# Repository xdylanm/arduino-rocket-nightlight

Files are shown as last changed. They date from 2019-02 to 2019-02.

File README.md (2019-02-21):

# Space Shuttle Nightlight

Based on the [low poly space shuttle nightlight](https://www.thingiverse.com/thing:2957683) by [kelvin8r](https://www.thingiverse.com/kelvin8r). 

## Modifications

* Remixed the base print without supports (buttons are printed separately and glued on, so it prints upside down). Also re-sized the opening to hold an Adafruit Circuit Playground.
* Eventually used the [Digispark board](http://digistump.com/products/1) (I use a clone that works off of micro USB)
* Code to drive neo pixels supports a different color palette and different animations. Mode switching is triggered by [capacitive touch](https://playground.arduino.cc/Main/CapacitiveSensor)
* Printed on [Anycubic I3 Mega](http://www.anycubic3d.com/)
** Black base, white shuttle/exhaust

## Notes

* The digispark board (ATTiny85 based) with the micronucleus bootloader has a long delay (5s) between power on and the start of the program. When connected via USB, this is fine (the bootloader seems to look for a host and when it finds one, all is good). When _powered_ off the USB (e.g. through a wall plug), nothing happens for 5s+ -- don't panic.
* The digispark board recycles a couple of pins for USB. Those pins are not suitable for capacitive touch. They can drive the neo pixels, but can also put the pixels in an odd state when running data over the USB.
* Follow the printing instructions from the [make](https://www.thingiverse.com/thing:2957683) carefully:
  * Exhaust: _no infill_, 0.2mm layer, 0.4mm (2x) bottom layer, 1.2mm (6x) walls
  * Shuttle: 25% infill, 0.2mm layer (or whatever)
  * Base: 20% infill, 0.2mm layer (or whatever) -- print upside down to avoid supports

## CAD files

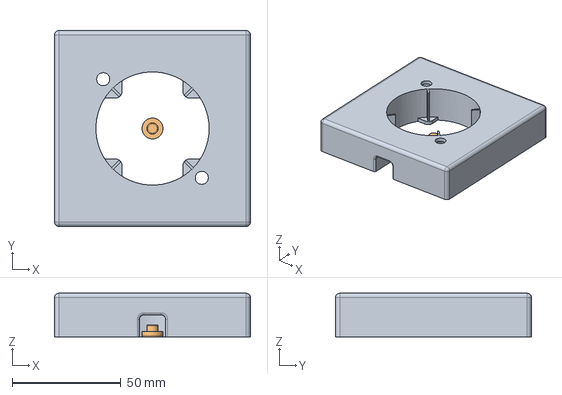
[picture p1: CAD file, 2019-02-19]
cad/circuit-playground-base.fcstd
90.0 x 90.0 x 20.0 mm

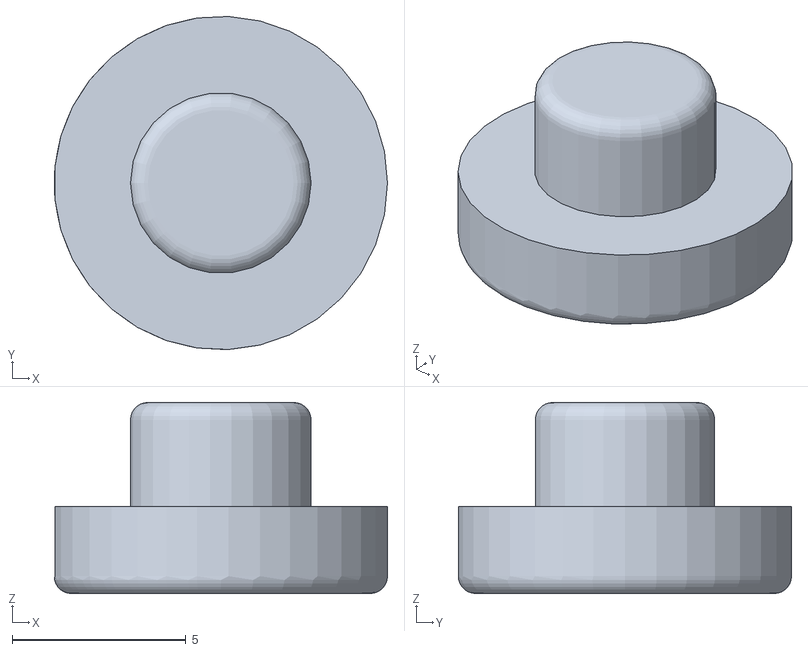
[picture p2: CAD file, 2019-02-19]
cad/rocket_base_circuit_playground_bump.stl
9.59 x 9.59 x 5.50

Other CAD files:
cad/rocket_base_circuit_playground.stl

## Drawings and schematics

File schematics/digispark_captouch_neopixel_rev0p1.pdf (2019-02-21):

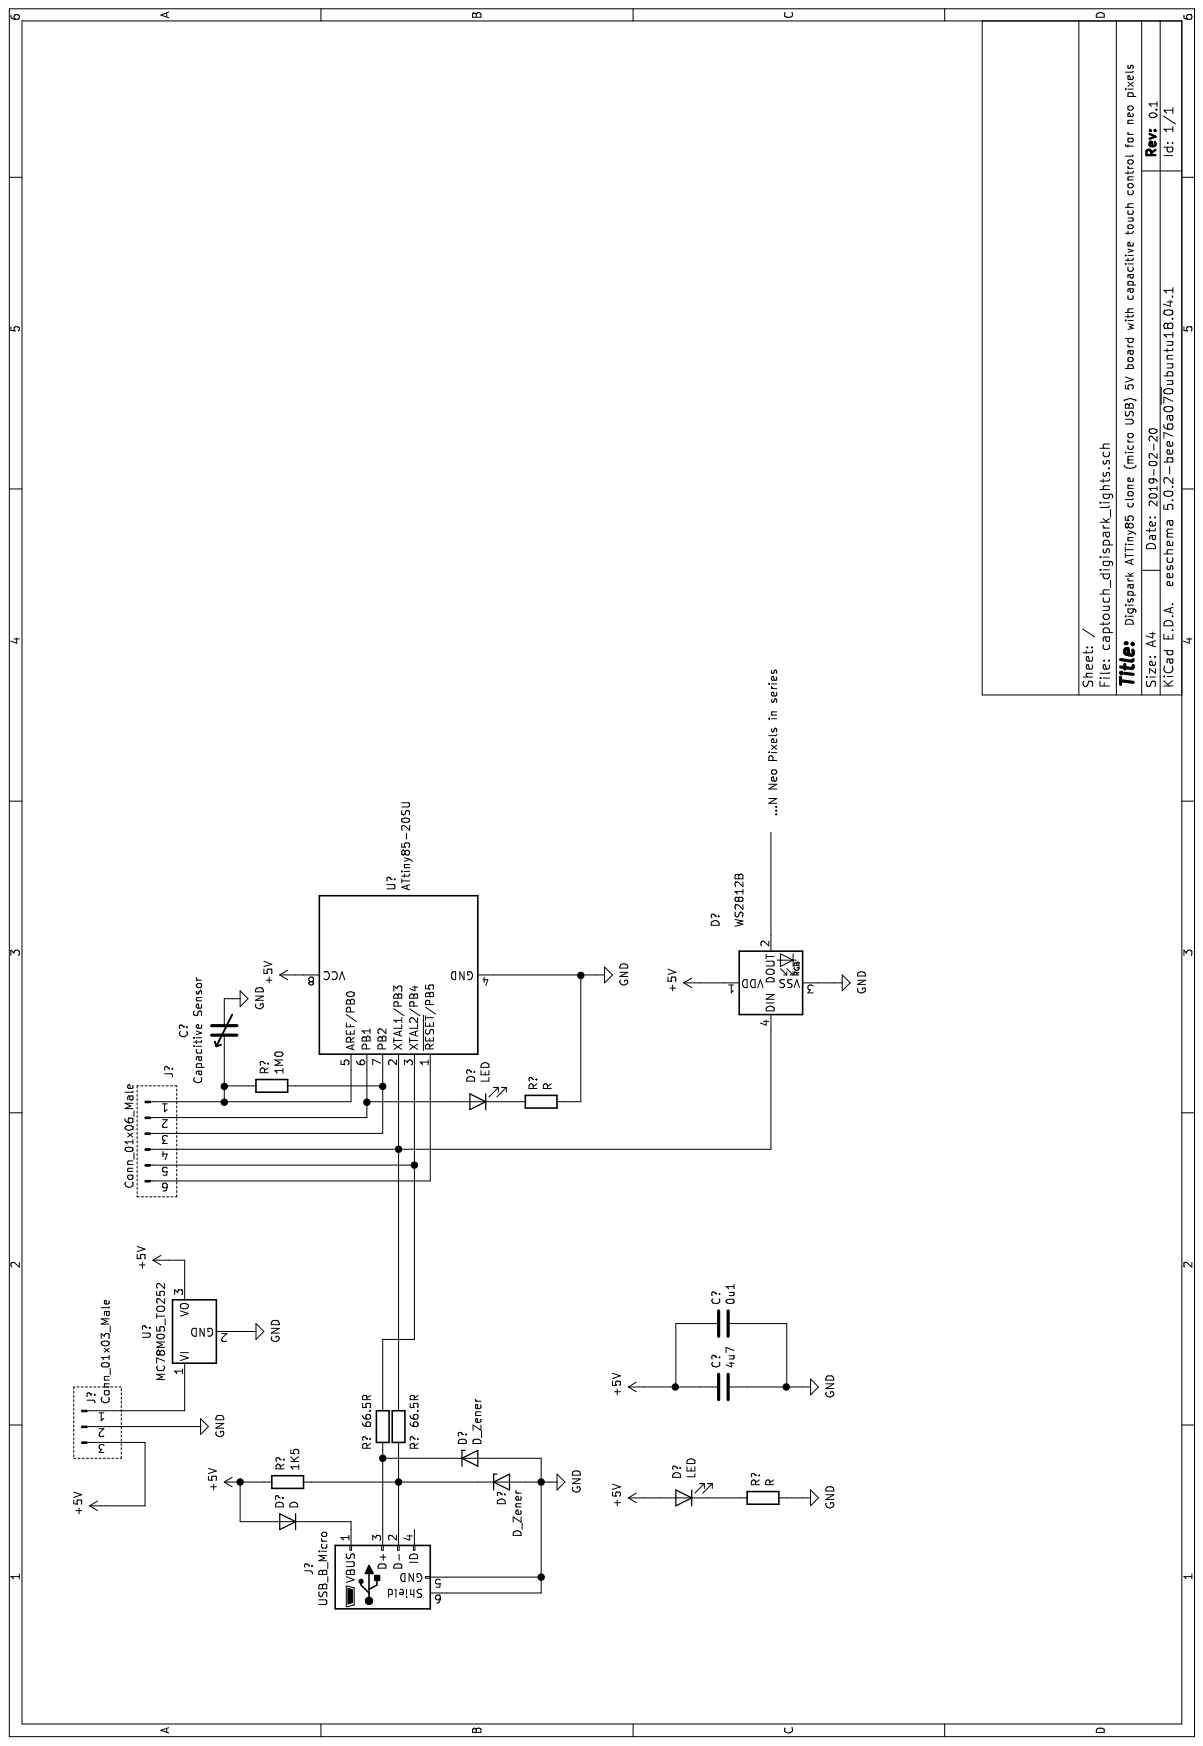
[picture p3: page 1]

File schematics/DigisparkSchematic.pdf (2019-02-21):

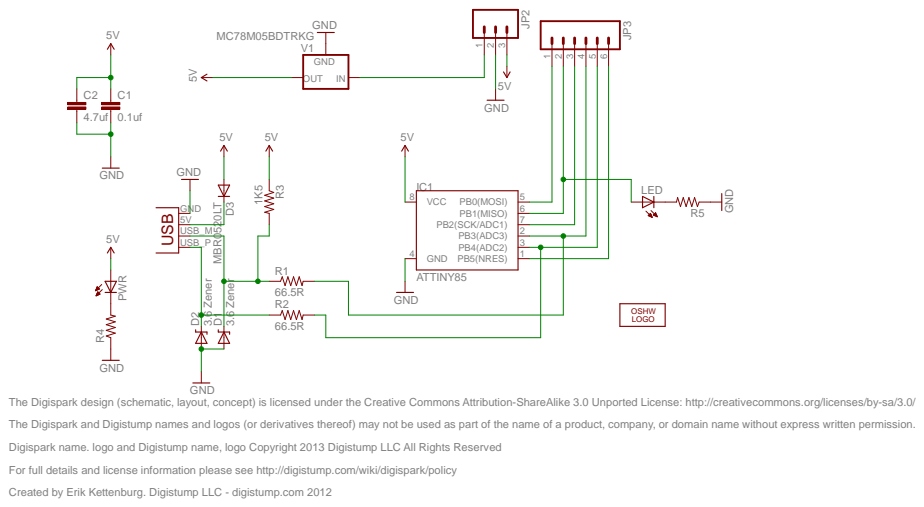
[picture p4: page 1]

The Digispark design (schematic, layout, concept) is licensed under the Creative Commons Attribution-ShareAlike 3.0 Unported License: http://creativecommons.org/licenses/by-sa/3.0/
The Digispark and Digistump names and logos (or derivatives thereof) may not be used as part of the name of a product, company, or domain name without express written permission.
Digispark name. logo and Digistump name, logo Copyright 2013 Digistump LLC All Rights Reserved
For full details and license information please see http://digistump.com/wiki/digispark/policy
Created by Erik Kettenburg. Digistump LLC - digistump.com 2012

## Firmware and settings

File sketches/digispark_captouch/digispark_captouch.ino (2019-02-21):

#include <Adafruit_NeoPixel.h>
#include <CapacitiveSensor.h>

#define PIN_DATA 4          // DIN to Neo Pixels
#define PIN_LED 1           // LED on Model B=PIN0, LED on Model A=PIN1
#define PIN_SENSE_READ 0    // Read for capacitive sensor
#define PIN_SENSE_DRIVE 2   // Drive V for capacitive sensor

#define N_PIXELS 6          // no more than 31

// threshold to detect a capacitive touch (0-999)
#define CAP_THRESHOLD 50 

// number of samples for capacitive sensor
#define CAP_NUM_SAMPLES 10 

// debounce timing (ms)
#define DEBOUNCE_MS 250 

#define PULSE_MS 125

// time to turn off (ticks = 1000/DEBOUNCE_MS*60*# minutes)
#define AUTO_OFF_TIMEOUT_TICKS 4800
uint32_t timeout_counter = 0;

// colors
const uint32_t palette[] = {
  0x8B0000, // dark red
  0xB22222, // firebrick
  0xFF0000, // red
  0xDC143C, // crimson
  0xFF6347, // tomato
  0xFF4500, // orange red
  0xFF8C00, // dark orange
  0xFFA500, // orange
  0xFFD700, // gold
  0xFFFF00, // yellow
  0xFFFFE0, // light yellow
  0xFFFACD  // lemon chiffon
};
uint8_t const num_colors = sizeof(palette)/sizeof(uint32_t);

int8_t pixel_color_index[N_PIXELS];
int8_t pixel_color_brightness[N_PIXELS];

enum NightLightMode {OFF=0, TWINKLE, PULSE, PULSE_OFF, NUM_MODES} night_light_state;
uint8_t pulse_level = 0;


Adafruit_NeoPixel pixels (N_PIXELS,PIN_DATA,NEO_GRBW+NEO_KHZ800);
CapacitiveSensor cap_sensor (PIN_SENSE_DRIVE, PIN_SENSE_READ);

bool cap_button_clicked() {
  long const val = cap_sensor.capacitiveSensor(CAP_NUM_SAMPLES); 
  return (val > CAP_THRESHOLD);
}

uint32_t scaled_color_quarter(uint8_t ipix, uint8_t num) {
  if (num == 4) {
    return palette[pixel_color_index[ipix]];
  } else if (num == 0) {
    return 0; 
  } else {
    uint8_t red   = (uint8_t)(palette[pixel_color_index[ipix]] >> 16);
    uint8_t green = (uint8_t)(palette[pixel_color_index[ipix]] >> 8);
    uint8_t blue  = (uint8_t)(palette[pixel_color_index[ipix]] >> 0);

    if (num == 2) {
      red   = red >> 1;
      green = green >> 1;
      blue  = blue >> 1;
    } else if (num == 1) {
      red   = red >> 2;
      green = green >> 2;
      blue  = blue >> 2;
    } else if (num == 3) {
      red   -= (red >> 2);
      green -= (green >> 2);
      blue  -= (blue >> 2);
    }
    return ((uint32_t)red << 16) | ((uint32_t)green << 8) | ((uint32_t)blue << 0);    
  }
}

void update_lights() 
{
  if (night_light_state == TWINKLE) {
    uint32_t brighten_mask = 0;
  
    long const nchange = random(N_PIXELS);  // brighten this many pixels
    for(long idelta = 0; idelta < nchange; ++idelta) {
      long const ipix = random(N_PIXELS);   // brighten this pixel
      brighten_mask |= 0x01 << ipix;
    }

    // saturating brighten/darken, then update 
    for(uint8_t ipix = 0; ipix < N_PIXELS; ++ipix) {
      if (brighten_mask & (0x01 << ipix)) {
        if ( pixel_color_brightness[ipix] < 3 ) { // 2 or lower --> 4
          pixel_color_brightness[ipix] += 2;
        } else if (pixel_color_brightness[ipix] > 5) {  // 6 or higher --> 4
          pixel_color_brightness[ipix] -= 2;
        } else {
          pixel_color_brightness[ipix] = 4;
        }
      } else {
        if ( pixel_color_brightness[ipix] > 1 && pixel_color_brightness[ipix] < 5 ) { // 2 to 4 --> 0
          pixel_color_brightness[ipix] -= 2;
        } else if (pixel_color_brightness[ipix] == 5) {  // 5 --> 8
          pixel_color_brightness[ipix] += 2;
        } else {
          pixel_color_brightness[ipix] = 0;
        }
       
        if (pixel_color_brightness[ipix] == 0) {  // change the color 
          pixel_color_index[ipix] = random(num_colors); 
        }
      }
    }
  } else if (night_light_state == PULSE) {
    if (pixel_color_brightness[0] == 0) { // new colors at 0
      for (uint8_t ipix = 0; ipix < N_PIXELS; ++ipix) {
        pixel_color_index[ipix] = random(num_colors); 
      }
    }

    for (uint8_t ipix = 0; ipix < N_PIXELS; ++ipix) {
      pixel_color_brightness[ipix] = (pixel_color_brightness[ipix] + 1) % 8;
    }
  } else if (night_light_state == PULSE_OFF) {
    bool all_off = true;
    for (uint8_t ipix = 0; ipix < N_PIXELS; ++ipix) {
      if (pixel_color_brightness[ipix] != 0) {      
        all_off = false;
        pixel_color_brightness[ipix] = (pixel_color_brightness[ipix] + 1) % 8;
      }
    }
    if (all_off) {
      night_light_state = OFF;
    }
  }

  for (uint8_t ipix = 0; ipix < N_PIXELS; ++ipix) {
    if (pixel_color_brightness[ipix] > 4) {
      pixels.setPixelColor(ipix,scaled_color_quarter(ipix,8-pixel_color_brightness[ipix]));
    } else {
      pixels.setPixelColor(ipix,scaled_color_quarter(ipix,pixel_color_brightness[ipix]));
    }
  }
  pixels.show();

}


void setup() 
{
  pinMode(PIN_LED, OUTPUT); 
  pinMode(PIN_SENSE_READ, INPUT);
  pinMode(PIN_SENSE_DRIVE, OUTPUT);
  pixels.begin();
  delay(500);
  for (int p = 0; p < N_PIXELS; ++p) {
    pixel_color_brightness[p] = 0; // off
    pixel_color_index[p] = random(num_colors); 
    pixels.setPixelColor(p,0);
  }
  pixels.show();

  timeout_counter = 0;
  night_light_state = OFF;
}


uint8_t toggle = 0;
bool cap_button_down = false;
void loop() 
{
    if (cap_button_clicked()) { // button down
      cap_button_down = true;
      digitalWrite(PIN_LED, toggle);
      toggle = (toggle == 0 ? 1 : 0);
      delay(DEBOUNCE_MS);
    } else if (cap_button_down) { // released
      cap_button_down = false;
      timeout_counter = 0;  // reset
      for (uint8_t ipix = 0; ipix < N_PIXELS; ++ipix) {
        pixel_color_brightness[ipix] = 0; // off
        pixel_color_index[ipix] = random(num_colors); 
      }

      if (night_light_state < PULSE) {
        night_light_state = (NightLightMode)(night_light_state + 1);
      } else {
        night_light_state = OFF;
      }
      delay(120);
    } else {
      delay(DEBOUNCE_MS/2);
    }

    if (night_light_state != OFF) {
      timeout_counter++;
      if (timeout_counter > AUTO_OFF_TIMEOUT_TICKS) {
        night_light_state = PULSE_OFF;
      } 
    }

    update_lights();

}

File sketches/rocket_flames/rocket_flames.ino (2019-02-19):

#include <Adafruit_CircuitPlayground.h>

uint32_t color_flame = 0;
uint32_t color_off = 0; 

class RocketFlames 
{
public:
  RocketFlames(Adafruit_CircuitPlayground& b) : m_board(b), m_brightness(5) { }

  void draw();
  void setBrightness(uint32_t b) { m_brightness = b; }

private:
  uint32_t saturatingAdd(uint32_t c1, uint32_t c2) const;
  uint32_t getFlameColorDelta() const;
    
private:
  Adafruit_CircuitPlayground& m_board;
  uint32_t m_brightness;
};

void RocketFlames::draw() 
{
  m_board.clearPixels();
  for (int ipix = 0; ipix < 10; ++ipix) {
    uint32_t const color_delta = getFlameColorDelta();
    uint32_t const next_color = saturatingAdd(color_delta, m_board.strip.getPixelColor(ipix));
    m_board.setPixelColor(ipix, next_color);
  }
}

uint32_t RocketFlames::getFlameColorDelta() const
{
  uint8_t const rpeak = 16*m_brightness;  // 16 to 240
  uint8_t const gpeak = 4*m_brightness;   // 4 to 64
  uint8_t shift = (uint8_t)random(rpeak);
  uint8_t const r = (shift > rpeak ? 0 : rpeak - shift);
  shift /= 4; 
  uint8_t const g = (shift > gpeak ? 0 : gpeak - shift);
  return m_board.strip.Color(r, g, 0);
}

uint32_t RocketFlames::saturatingAdd(uint32_t c1, uint32_t c2) const
{
  uint8_t const r1 = (uint8_t)(c1 >> 16);
  uint8_t const g1 = (uint8_t)(c1 >> 8);
  uint8_t const b1 = (uint8_t)(c1 >> 0);

  uint8_t const r2 = (uint8_t)(c2 >> 16);
  uint8_t const g2 = (uint8_t)(c2 >> 8);
  uint8_t const b2 = (uint8_t)(c2 >> 0);

  return m_board.strip.Color(
    constrain(r1+r2,0,255),
    constrain(g1+g2,0,255),
    constrain(b1+b2,0,255));
}

RocketFlames flames (CircuitPlayground);

void setup() 
{
  Serial.begin(9600);
  Serial.println("Blast off!");

  CircuitPlayground.begin();
}

void loop() 
{
  for (int b = 5; b < 10; ++b) {
    flames.setBrightness(b);
    for (int flicker = 0; flicker < 4; ++flicker) {
      flames.draw();
      delay(random(100,250));
    }
  }
  for (int b = 9; b >= 5; --b) {
    flames.setBrightness(b);
    for (int flicker = 0; flicker < 4; ++flicker) {
      flames.draw();
      delay(random(100,250));
    }
  }
}

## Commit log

2018-11-17 initial sketch of rocket flame pixel pattern for Circuit Playground
2019-02-19 added CAD files for updated rocket base for circuit playground. Added new Arduino sketch for driving neo pixels from a Digispark board, supports capacitive touch for modes
    [circuit-playground-base.fcstd, rocket_base_circuit_playground.stl, rocket_base_circuit_playground_bump.stl]
2019-02-21 sketch update with new pixel count, animation updates, tested and deployed on Digispark. Added schematic for digispark board with capacitive touch sensor and neo pixel string
    [captouch_digispark_lights.sch]
